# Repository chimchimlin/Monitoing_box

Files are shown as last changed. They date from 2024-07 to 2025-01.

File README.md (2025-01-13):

# 智慧森林: 基於 LoRa 的火災監測與數據分析平台

## 說明
智慧森林是一個火災監測與數據分析平台，透過物聯網技術（IoT）來即時監控森林環境中的溫度、濕度、氣壓及揮發性有機物（VOC）等關鍵指標，以預防火災和監控環境變化。  
該平台使用 LoRa 無線通訊技術來實現長距離、低功耗的感測資料傳輸，適合應用於廣大且偏遠的森林地區。  

## 架構
前端: `vue3`  
後端: `Node.js`, `MQTT`, `MariaDB`  
感測器: `Bosch BME680`, `ESP32 heltec wireless stick lite v3`, `LoRaWAN`  

使用 BME680 讀取環境資料，並由 ESP32 上搭載的 LoRa 協定發送至 IoT gateway，再由 IoT gateway 使用 MQTT 發送至後端 server 中。  
前端再藉由 RESTful API 向後端獲取當前所有感測節點資料並顯示於地圖上。

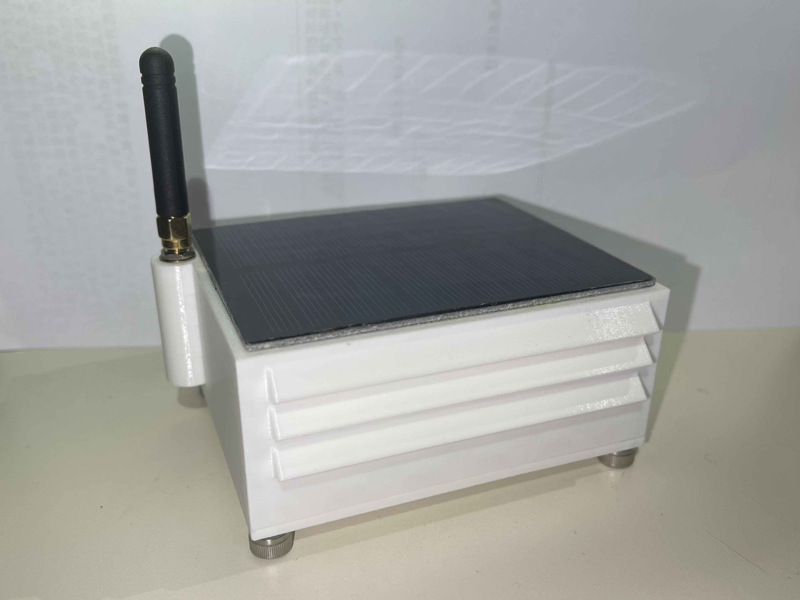
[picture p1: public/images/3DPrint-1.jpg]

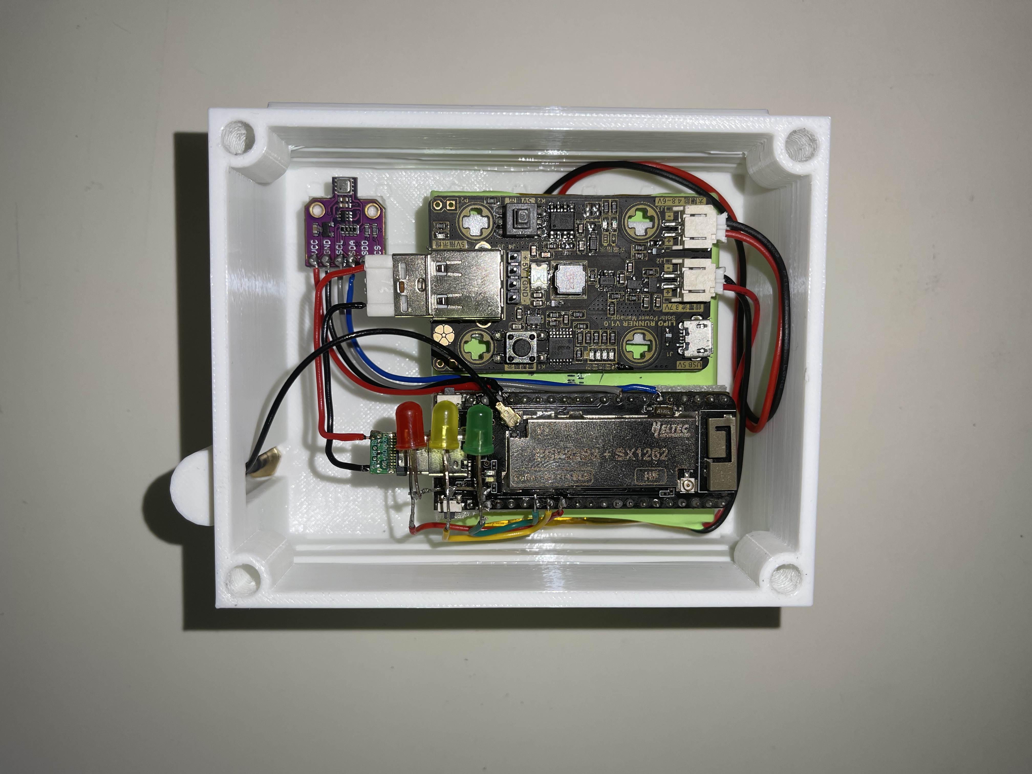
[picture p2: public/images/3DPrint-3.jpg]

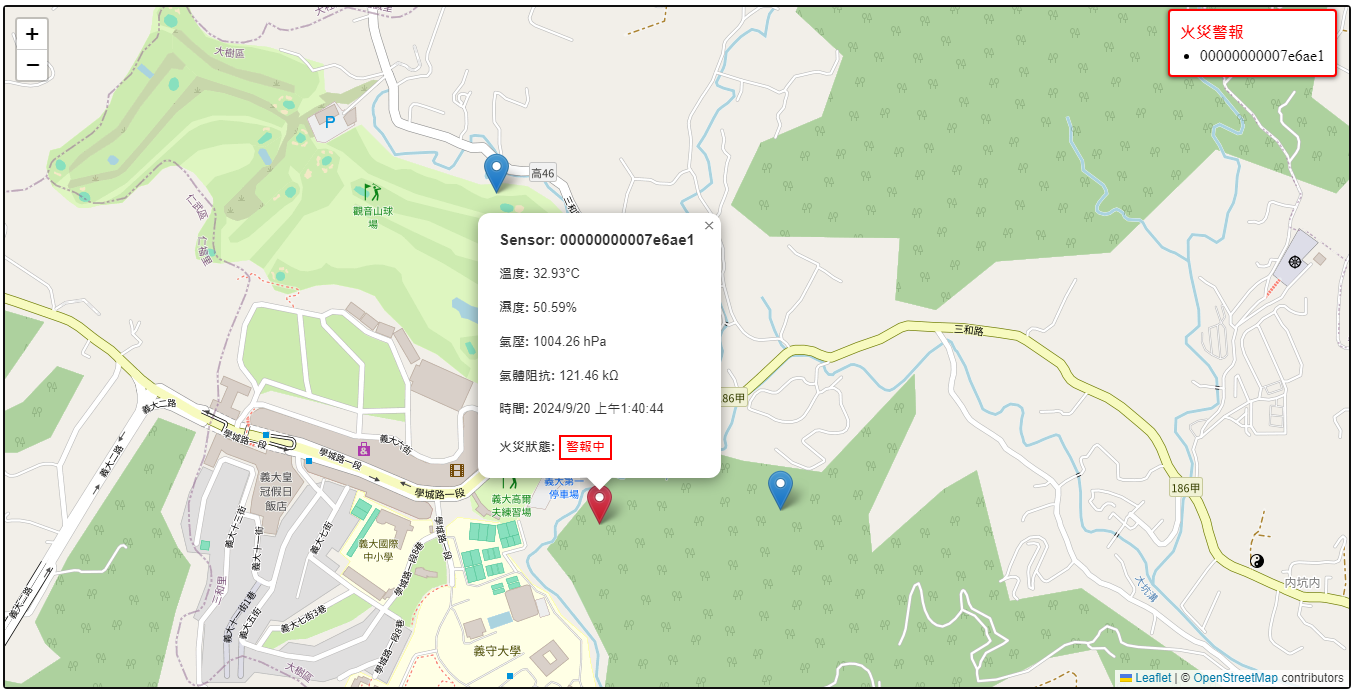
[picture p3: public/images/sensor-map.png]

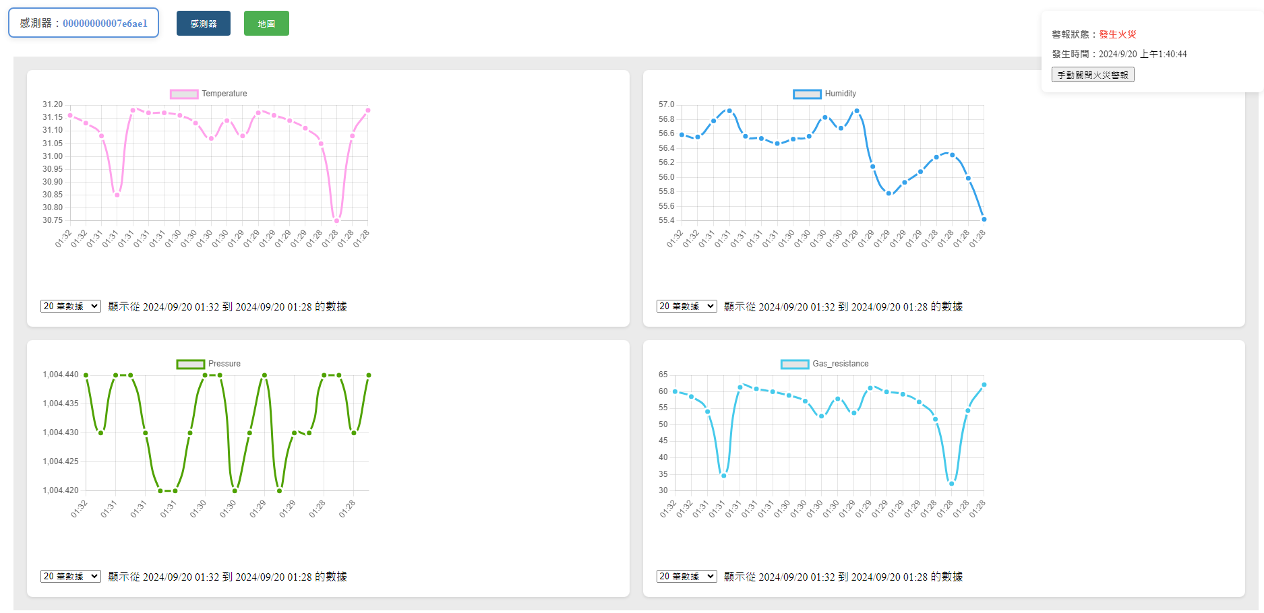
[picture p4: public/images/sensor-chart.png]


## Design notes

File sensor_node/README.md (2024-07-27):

# 感測節點

### 開發板管理網址
```
https://github.com/Heltec-Aaron-Lee/WiFi_Kit_series/releases/download/1.0.0/package_heltec_esp32_index.json
```

### 開發板選擇
安裝 [`Heltec ESP32 Series Dev-boards`](https://github.com/Heltec-Aaron-Lee/WiFi_Kit_series)  
選擇 `WiFi LoRa 32(V3)/Wireless shell(V3)/Wireless stick lite (V3)` 開發板  

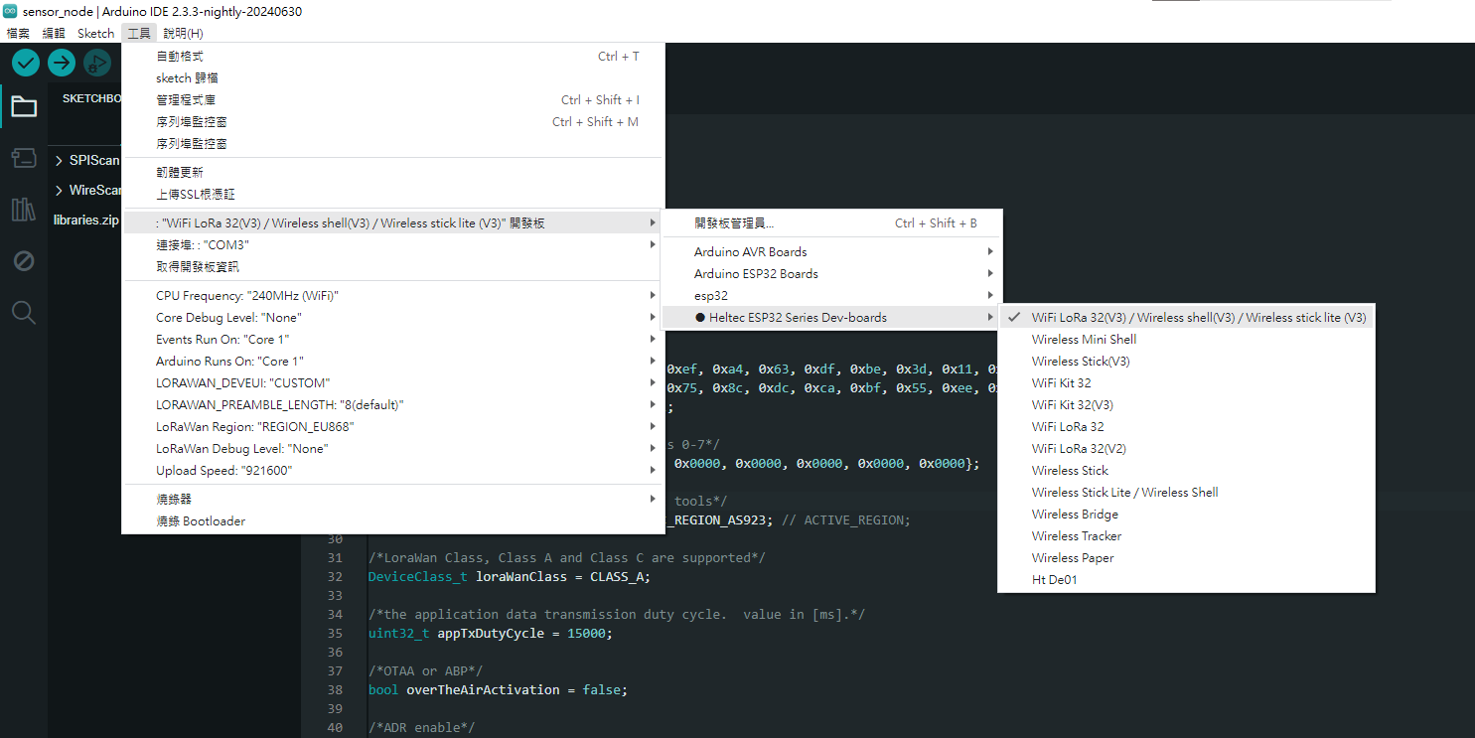
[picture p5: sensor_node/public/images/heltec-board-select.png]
  

### 需求函式庫
```
LoRaWan_APP.h
```
> `LoRaWan_APP.h` 在 Arduino IDE 安裝時有內建  
> 可能路徑 **C:\Users\user\AppData\Local\Arduino15\packages\Heltec-esp32\hardware\esp32\1.0.0\libraries\LoraWan102\src\LoRaWan_APP.h**

### 其他設置
`loraWanRegion` 只有在程式碼中設置 **LORAMAC_REGION_AS923** 沒用，還需在 Arduino IDE > 工具 中設置，不然編譯成功後運行只會卡在 spi timeout  

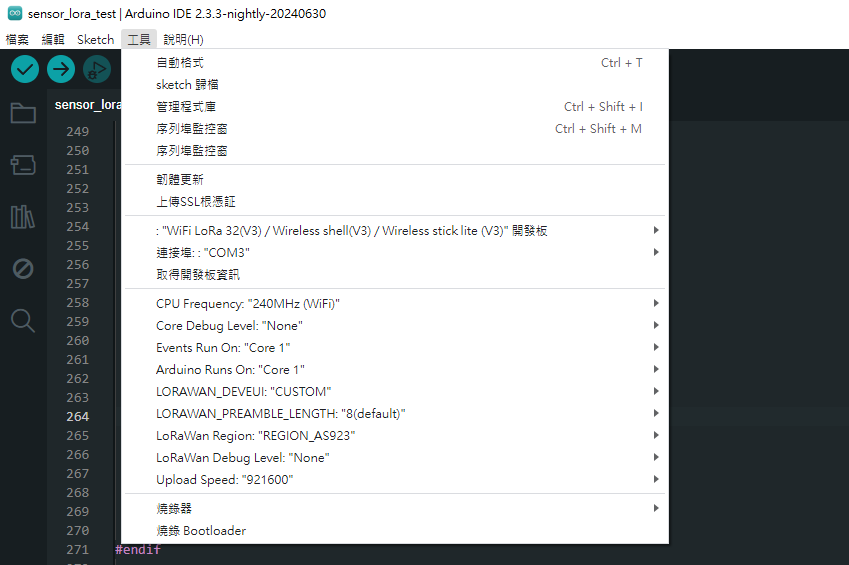
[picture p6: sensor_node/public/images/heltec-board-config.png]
  

`LoRaWan_APP.h` 使用 ABP 模式仍須設置 OTAA 參數，不然會編譯失敗 :)

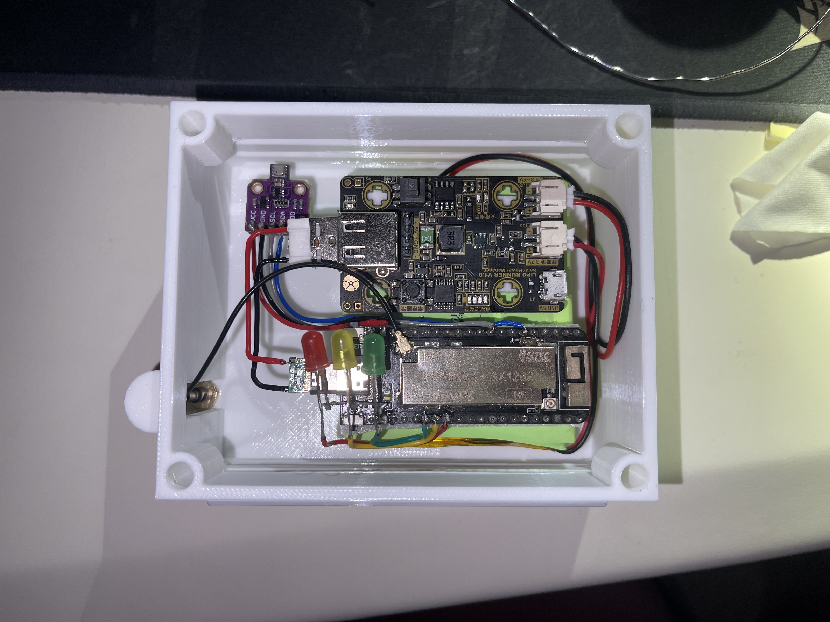
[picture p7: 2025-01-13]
public/images/3DPrint-5.jpg

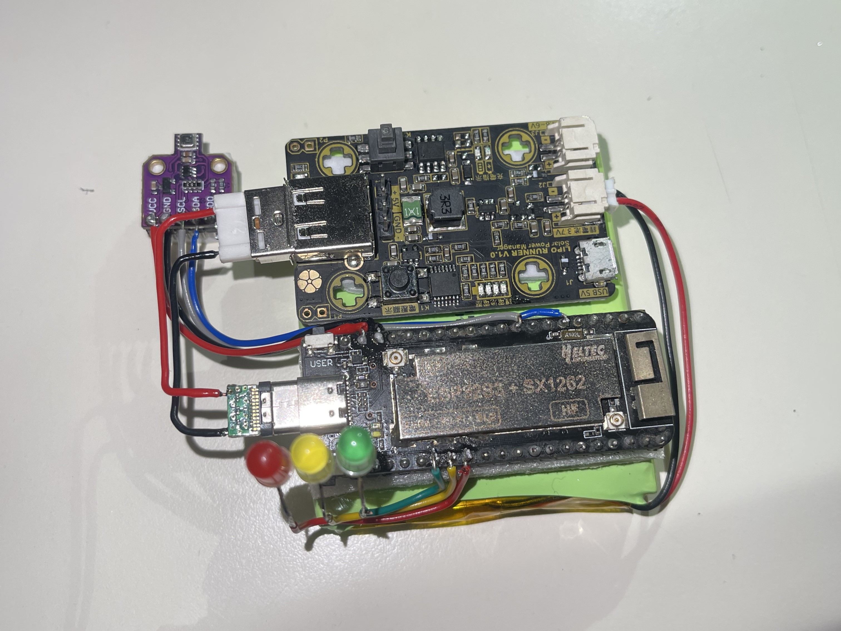
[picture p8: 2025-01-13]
public/images/3DPrint-4.jpg

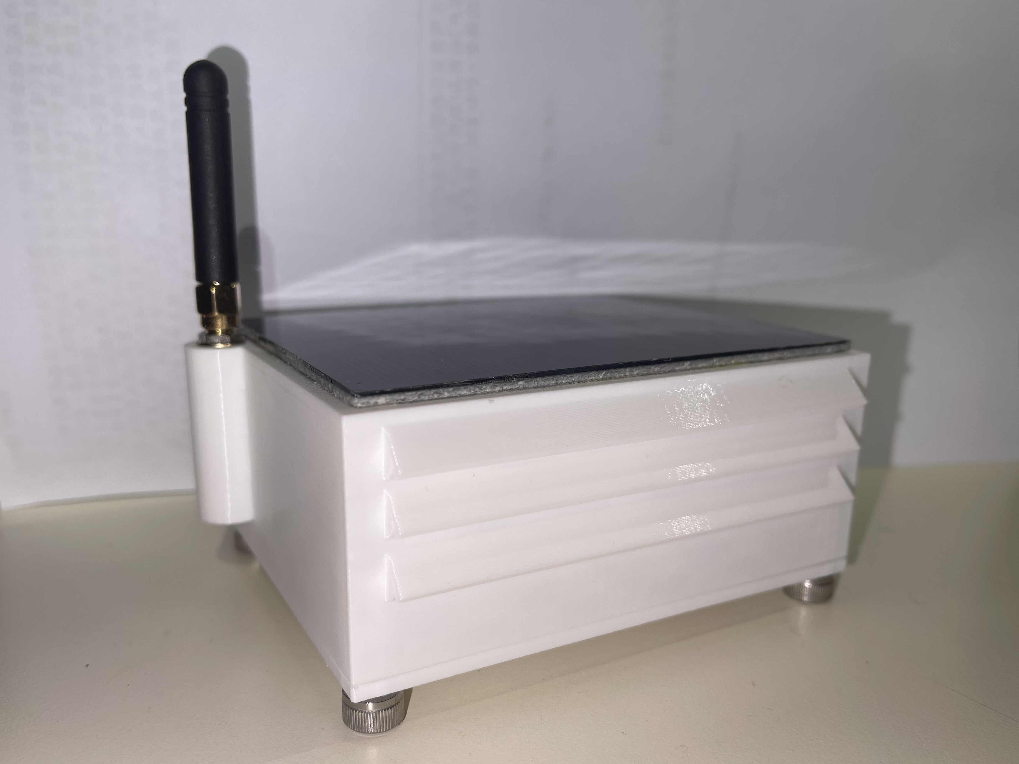
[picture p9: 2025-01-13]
public/images/3DPrint-2.jpg

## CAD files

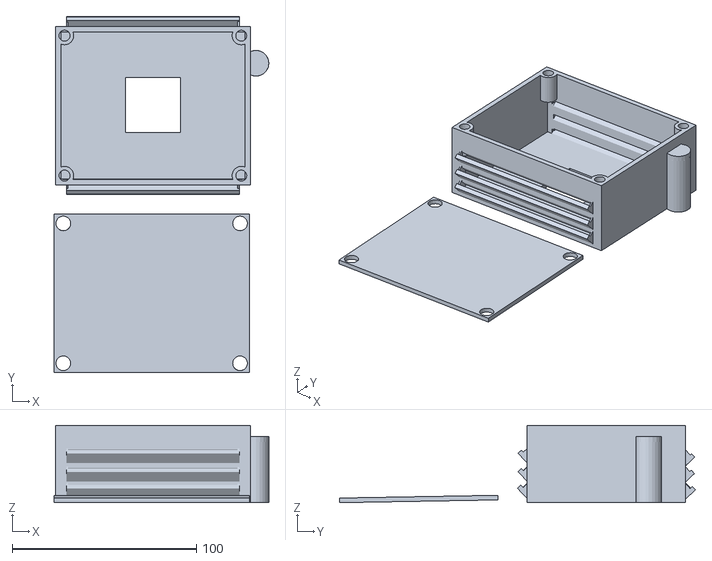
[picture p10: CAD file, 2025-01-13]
public/stl/sensor-node.stl
116.7 x 193.3 x 42.0

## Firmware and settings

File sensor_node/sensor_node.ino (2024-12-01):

/**
 * 獲取 BME680 感測器資料
 * LoRaWan 上傳 server (使用 ABP mode)
 */

#include <Wire.h>
#include <LittleFS.h>
#include "LoRaWan_APP.h"

#include "src/lib/BME680.h"
#include "src/lib/heltec_vbat.h"
#include "src/config/config.h"
#include "src/lib/model.h"


/* OTAA para*/
uint8_t devEui[] = {0x22, 0x32, 0x33, 0x00, 0x00, 0x88, 0x88, 0x02};
uint8_t appEui[] = {0x00, 0x00, 0x00, 0x00, 0x00, 0x00, 0x00, 0x00};
uint8_t appKey[] = {0x88, 0x88, 0x88, 0x88, 0x88, 0x88, 0x88, 0x88, 0x88, 0x88, 0x88, 0x88, 0x88, 0x88, 0x88, 0x88};

/* ABP para*/
uint8_t nwkSKey[16] = NWK_SKEY;
uint8_t appSKey[16] = APP_SKEY;
uint32_t devAddr = (uint32_t)DEV_ADDR;

/*LoraWan channelsmask, default channels 0-7*/
uint16_t userChannelsMask[6] = {0x00FF, 0x0000, 0x0000, 0x0000, 0x0000, 0x0000};

/*LoraWan region, select in arduino IDE tools*/
LoRaMacRegion_t loraWanRegion = LORAMAC_REGION_AS923; // ACTIVE_REGION;

/*LoraWan Class, Class A and Class C are supported*/
DeviceClass_t loraWanClass = CLASS_A;

/*the application data transmission duty cycle.  value in [ms].*/
uint32_t appTxDutyCycle = LORA_SEND_INTERVAL;

/*OTAA or ABP*/
bool overTheAirActivation = false;

/*ADR enable*/
bool loraWanAdr = true;

/* Indicates if the node is sending confirmed or unconfirmed messages */
bool isTxConfirmed = true;

/* Application port */
uint8_t appPort = 2;

/*!
 * Number of trials to transmit the frame, if the LoRaMAC layer did not
 * receive an acknowledgment. The MAC performs a datarate adaptation,
 * according to the LoRaWAN Specification V1.0.2, chapter 18.4, according
 * to the following table:
 *
 * Transmission nb | Data Rate
 * ----------------|-----------
 * 1 (first)       | DR
 * 2               | DR
 * 3               | max(DR-1,0)
 * 4               | max(DR-1,0)
 * 5               | max(DR-2,0)
 * 6               | max(DR-2,0)
 * 7               | max(DR-3,0)
 * 8               | max(DR-3,0)
 *
 * Note, that if NbTrials is set to 1 or 2, the MAC will not decrease
 * the datarate, in case the LoRaMAC layer did not receive an acknowledgment
 */
uint8_t confirmedNbTrials = 4;


/* Prepares the payload of the frame */
static void prepareTxFrame(uint8_t* data)
{
    appDataSize = SENSOR_DATA_SIZE;
    memcpy(appData, data, SENSOR_DATA_SIZE);
}




BME680 bme(Wire);
BME680Data sensorData;
uint8_t payload[SENSOR_DATA_SIZE];      // Sensor data
float vbat = -1;                        // Battery voltage
double output[2];


void getBME680Readings()
{
    digitalWrite(DATA_LED, HIGH);

    // Tell BME680 to begin measurement.
    unsigned long endTime = bme.beginReading();

    digitalWrite(DATA_LED, LOW);

    if (endTime == 0)
    {
        Serial.println("[BME680] Failed to begin reading :(");
        int stoptime;
        stoptime = millis();
        errLeds(stoptime);
    }
    if (!bme.endReading())
    {
        Serial.println("[BME680] Failed to complete reading :(");
        int stoptime;
        stoptime = millis();
        errLeds(stoptime);
    }

    sensorData.temperature = bme.temperature;
    sensorData.pressure = bme.pressure / 100.0;
    sensorData.humidity = bme.humidity;
    sensorData.gasResistance = bme.gas_resistance / 1000.0;

    double input[3] = {
        (double)sensorData.temperature,
        (double)sensorData.humidity,
        (double)sensorData.gasResistance
    };

    score(input, output);
}

/**
 * Restart ESP32
 */
void softwareReset()
{
    esp_restart();
}

void errLeds(int stoptime)
{
    int nowtime, over;
    while (1)
    {
        nowtime = millis();

        digitalWrite(PANIC_LED, HIGH);
        delay(ERROR_DURATION);
        digitalWrite(PANIC_LED, LOW);
        delay(ERROR_DURATION);

        over = nowtime - stoptime;

        if (over > ERROR_LOOP_TIME)
        {
            softwareReset();
        }
    }
}

/**
 * 將 float 轉換為 16 進位
 */
void floatToHex(float value, uint8_t* buffer)
{
    int intValue = *(int*)&value;   // 將 float 轉換為 int 表示

    buffer[0] = (intValue >> 24) & 0xFF;
    buffer[1] = (intValue >> 16) & 0xFF;
    buffer[2] = (intValue >> 8) & 0xFF;
    buffer[3] = intValue & 0xFF;
}

/**
 * 將資料使用 LittleFS 寫入 ESP32 txt 中
 */
void logDataToFile(const char* filename, BME680Data data, float batteryPercent)
{
    File file = LittleFS.open(filename, FILE_APPEND);

    if (!file)
    {
        Serial.println("[LittleFS] Failed to open file for appending");
        return;
    }

    // Format the data as a CSV line
    file.printf("%f,%f,%f,%f,%f\n", 
                data.temperature, 
                data.humidity, 
                data.pressure, 
                data.gasResistance, 
                batteryPercent);

    file.close();

    Serial.println("[LittleFS] Data logged successfully");
}


void setup()
{
    Serial.begin(115200);
    Serial.println("----- start init -----");


    // LittleFS
#if (ENABLE_WRITE_TO_TXT)
    Serial.println("[LittleFS] Initialize LittleFS");

    if (!LittleFS.begin(true)) 
    {
        int stoptime;
        stoptime = millis();
        Serial.println("[LittleFS] Failed to mount LittleFS");
        errLeds(stoptime);
    }

    Serial.println("[LittleFS] LittleFS mounted successfully");
#endif


    // LED pin
    pinMode(RUNNING_LED, OUTPUT);
    pinMode(DATA_LED, OUTPUT);
    pinMode(PANIC_LED, OUTPUT);
    digitalWrite(RUNNING_LED, HIGH);
    digitalWrite(DATA_LED, LOW);
    digitalWrite(PANIC_LED, LOW);


    Serial.println("[LoRa] Initialize LoRaWan_APP");
    Mcu.begin();
    deviceState = DEVICE_STATE_INIT;


    Serial.println("[BME680] Initialize sensor");
    bme.setSPIPins(BME_SDA_PIN, BME_SCL_PIN);
    memset(payload, 0xFF, sizeof(payload));     // Default value


    // Init BME680 sensor
    if (!bme.begin())
    {
        int stoptime;
        stoptime = millis();
        Serial.println("[BME680] Could not find a valid BME680 sensor, check wiring!");
        errLeds(stoptime);
    }

    // Set up oversampling and filter initialization
    bme.setTemperatureOversampling(BME680_OS_8X);
    bme.setHumidityOversampling(BME680_OS_2X);
    bme.setPressureOversampling(BME680_OS_4X);
    bme.setIIRFilterSize(BME680_FILTER_SIZE_3);
    bme.setGasHeater(320, 150); // 320*C for 150 ms

    delay(50);
    getBME680Readings();    // Test get sensor data

    Serial.println("[BME680] Successfully initialized sensor");


    Serial.println("----- init ok -----");
}


void loop()
{
     switch (deviceState)
    {
    case DEVICE_STATE_INIT:
    {

#if (LORAWAN_DEVEUI_AUTO)
        LoRaWAN.generateDeveuiByChipID();
#endif

        LoRaWAN.init(loraWanClass, loraWanRegion);
        break;
    }
    case DEVICE_STATE_JOIN:
    {
        LoRaWAN.join();
        break;
    }
    case DEVICE_STATE_SEND:
    {
        vbat = heltec_vbat();
        int battery_percent = heltec_battery_percent(vbat);

        getBME680Readings();    // Get sensor data


#if (ENABLE_WRITE_TO_TXT)
        logDataToFile(TXT_FILE_PATH, sensorData, battery_percent);  // Log to file
#endif


#if (DEBUG_MODE)
        Serial.printf("Temperature = %f ºC \n", sensorData.temperature);
        Serial.printf("Humidity = %f % \n", sensorData.humidity);
        Serial.printf("Pressure = %f hPa \n", sensorData.pressure);
        Serial.printf("Gas Resistance = %f KOhm \n", sensorData.gasResistance);
        Serial.printf("Vbat = %.2fV (%d%%)\n", vbat, heltec_battery_percent(vbat));
        Serial.println();
        Serial.println("--------------");
#endif


        // Convert float data to hex
        floatToHex(sensorData.temperature, payload);            // 轉換溫度
        floatToHex(sensorData.humidity, payload + 4);           // 轉換濕度
        floatToHex(sensorData.pressure, payload + 8);           // 轉換氣壓
        floatToHex(sensorData.gasResistance, payload + 12);     // 轉換氣體阻抗
        payload[16] = battery_percent;                          // 儲存剩餘電池電量%數

        // 火災判斷
        if (output[1] == output[0])
        {
            payload[17] = (sensorData.gasResistance > 36) ? 0 : 1;
        }
        else
        {
            payload[17] = (output[0] > output[1]) ? 0 : 1;
        }


#if (DEBUG_MODE)
        Serial.print("Temperature (hex): ");
        for (int i = 0; i < 4; ++i) {
            Serial.print(payload[i], HEX);
            // Serial.print(" ");
        }
        Serial.println();

        Serial.print("Humidity (hex): ");
        for (int i = 4; i < 8; ++i) {
            Serial.print(payload[i], HEX);
            // Serial.print(" ");
        }
        Serial.println();

        Serial.print("Pressure (hex): ");
        for (int i = 8; i < 12; ++i) {
            Serial.print(payload[i], HEX);
            // Serial.print(" ");
        }
        Serial.println();

        Serial.print("Gas Resistance (hex): ");
        for (int i = 12; i < 16; ++i) {
            Serial.print(payload[i], HEX);
            // Serial.print(" ");
        }
        Serial.println();

        Serial.print("Battery Percent : ");
        for (int i = 16; i < 17; ++i) {
            Serial.print(payload[i]);
            // Serial.print(" ");
        }

        Serial.println();

        Serial.print("Fire Predict: ");
        for (int i = 17; i < 18; ++i) {
            Serial.print(payload[i]);
            // Serial.print(" ");
        }

        Serial.println();
        Serial.println("--------------");
#endif

        // Send  payload
        prepareTxFrame(payload);
        LoRaWAN.send();

#if (DEBUG_MODE)
        Serial.println("------- End transmission -------");
#endif

        deviceState = DEVICE_STATE_CYCLE;

        txDutyCycleTime = appTxDutyCycle + randr(-APP_TX_DUTYCYCLE_RND, APP_TX_DUTYCYCLE_RND);
        LoRaWAN.cycle(txDutyCycleTime);
        deviceState = DEVICE_STATE_SLEEP;
        break;
    }
    case DEVICE_STATE_SLEEP:
    {
        digitalWrite(RUNNING_LED, LOW);
        LoRaWAN.sleep(loraWanClass);
        break;
    }
    default:
    {
        deviceState = DEVICE_STATE_INIT;
        break;
    }
    }
}

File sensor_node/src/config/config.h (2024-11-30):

/**
 * sensor_node.ino config file
*/

#ifndef CONFIG_H
#define CONFIG_H

#define DEBUG_MODE 1    // Debug mode, 0 or 1


/**
 * LoRaWAN ABP config
 */

// Network Session Key (16 bytes)
#define NWK_SKEY {0x15, 0xb1, 0xd0, 0xef, 0xa4, 0x63, 0xdf, 0xbe, 0x3d, 0x11, 0x18, 0x1e, 0x1e, 0xc7, 0xda, 0x85}

// Application Session Key (16 bytes)
#define APP_SKEY {0xd7, 0x2c, 0x78, 0x75, 0x8c, 0xdc, 0xca, 0xbf, 0x55, 0xee, 0x4a, 0x77, 0x8d, 0x16, 0xef, 0x67}

// Device Address (4 bytes)
#define DEV_ADDR 0x007e6ae1

// LoRaWAN 資料每次發送的時間間格, (ms)
#define LORA_SEND_INTERVAL (10 * 1000)  


/**
 * BME680 I2C pin define
*/
#define BME_SDA_PIN 16  // 藍
#define BME_SCL_PIN 17  // 紫

/* Cached BME680 sensor data */
typedef struct
{
    float temperature;
    float humidity;
    float pressure;
    float gasResistance;
} BME680Data;

#define SENSOR_DATA_SIZE 18     // Sensor data size to be sent


/**
 * LED setup
*/
#define RUNNING_LED GPIO_NUM_33     // 正常運作指示燈 (normal running)
#define DATA_LED GPIO_NUM_34        // 感測資料獲取中指示燈 (getting sensor data)
#define PANIC_LED GPIO_NUM_35       // 錯誤指示燈 (error)
#define ERROR_DURATION 1000         // PANIC_LED 閃爍間隔 (ms)
#define ERROR_LOOP_TIME 30000       // 錯誤重啟 PANIC_LED 閃爍時間


/**
 * 是否啟用將感測數據寫入 txt 文件。
 * 0: disable, 1: enable
 */
#define ENABLE_WRITE_TO_TXT 1

/**
 * LittleFS 寫入 ESP32 的 txt 路徑
 */
#define TXT_FILE_PATH "/sensor_data.txt"


#endif /* CONFIG_H */

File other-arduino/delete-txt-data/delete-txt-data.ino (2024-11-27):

/**
 * 刪除寫入的 TXT 資料
 * 
 */

#include <LittleFS.h>

#define TXT_FILE_PATH "/sensor_data.txt"


void clearFileContent()
{
    if (!LittleFS.begin())
    {
        Serial.println("Failed to initialize LittleFS");
        return;
    }

    // 檢查文件是否存在
    if (LittleFS.exists(TXT_FILE_PATH))
    {
        // 以寫入模式重新打開文件，這會清空文件內容
        File file = LittleFS.open(TXT_FILE_PATH, FILE_WRITE);

        if (file)
        {
            Serial.println("File content cleared.");
            file.close();
        }
        else
        {
            Serial.println("Failed to open file for writing.");
        }
    }
    else
    {
        Serial.println("File does not exist.");
    }

    LittleFS.end();
}

void setup() {
    Serial.begin(115200);
    clearFileContent();
}

void loop() 
{
}

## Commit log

2024-07-18 feat(api): Add get sensorList api
2024-07-20 refactor(sql): Update SensorData add DELETE CASCADE
2024-07-20 feat(api): Add sensor node add, delete, edit api
2024-07-27 refactor: Refactor sensor_node code & add debug led
2024-07-27 docs: Update sensor_node README
2024-08-01 chore(sql): Sensor table add battery record
2024-08-02 feat: Add MQTT module switch
2024-08-02 feat(api): sensorList add get battery value
2024-09-01 chore(sql): Update sensor table & update test sql
2024-09-01 refactor(api): Update sensorList api
2024-09-02 feat(api): Add sensor openFireNotify api
2024-09-12 更改 errled 超過30自動重啟
2024-09-28 fix: Fix sensor error loop restart time
    [config.h, sensor_node.ino]
2024-10-16 fix: Fix sensor config error
    [config.h]
2024-10-19 feat: Add fire simulation program & data
    [sensor-data.xlsx]
2024-10-19 feat: Add description field to sensor table
2024-11-27 feat: Add LittleFS to save sensor data to txt
2024-11-27 feat: Add read & delete ESP32 txt data function
2024-11-30 refactor(MQTT): Change to using sensor node to determine fire occurrence
2024-12-01 revise Serial.print()
2024-12-05 feat: Add is_fire record to SensorData
2024-12-22 fix(DB): Fix Sensor.last_firetime always refresh
2025-01-13 docs: Update README & sensor images
2025-01-13 chore: Add sensor stl file
    [sensor-node.stl]
